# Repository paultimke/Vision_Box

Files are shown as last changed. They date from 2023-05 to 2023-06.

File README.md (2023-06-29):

# Vision Box User Interface Quality Assessment System
The Vision Box is a Computer-Vision-based system designed to automate testing of screens during the development phases of a User Interface. The physical system consists of an enclosed box to ensure a light-controlled environment for any device introduced and containts an illumination system which can be set manually or automatically through the accompanying Desktop Command-Line application.

All commands supported by the Dekstop application can be displayed using the HELPME command. Some of the main commands for a testing session are:
- **FICON**: Find a specific icon or subimage embedded within a larger image
- **COMPIMAGE**: Compare two images for similarity, returning a total similarity score
- **FTEXT**: Find specific Ascii-based text (words, letters, sentences) within the screen

## Usage Example
Imagine you have created a new screen for the UI and have an image called 'test\_screen.png'. You also have an image of an asset you want to look for in that screen. The following example of a test session will look for the asset within the image, compare the device-under-test to the screen reference provided and look for the keyword "network" within the device-under-test:

```
TESTSTATUS(START)

Initializing Hardware

TEST STARTED
[PC] >> FICON("clock.png")
[VB] >> ACK FICON(clock.png)
[PC] >> COMPIMAGE("test_screen.png")
[VB] >> ACK COMPIMAGE(test_screen.png)
[PC] >> FTEXT("network")
[VB] >> ACK FTEXT(network)
[PC] >> TESTSTATUS(END)
[VB] >> ACK TESTSTATUS(END)

Waiting on commands to finish processing...
Test result: PASSED
```
The images used on the above session were the following:
images_dut

After the test, the following output images and log file will be produced:
<p float="left">
  output
</p>

## Images of the physical device built
physical

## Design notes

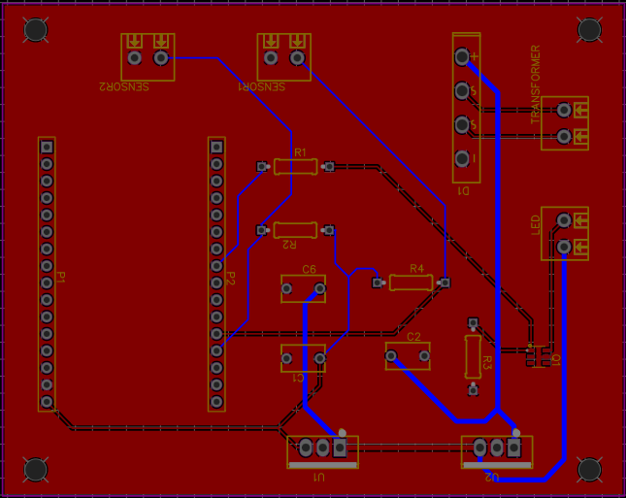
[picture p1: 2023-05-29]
Electrical/PCB_Design_brd_pdf.png

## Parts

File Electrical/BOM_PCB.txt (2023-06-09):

									
ID	Name	Designator	Quantity	Manufacturer Part	Manufacturer	Supplier	Supplier Part	Price	
1	4.7u	"C1,C6"	2	CCBCapacitor 100PF100v	ReliaPro	LCSC	C50140	0.048	
2	220u	C2	1	CCBCapacitor 100PF100v	ReliaPro	LCSC	C50140	0.048	
3	GBU406 Rectifier bridge	D1	1	GBU406	MDD	LCSC	C13432	0.19	
4	Screw_terminal_LED	E3	1	WJ350V-3.96-2P-14-00A	KANGNEX	LCSC	C3031444	0.081	
5	Header-Female-2.54_1x16	"P1,P2"	2	2.54-1*16P母	BOOMELE	LCSC	C66987	0.104	
6	SIL3439K	Q1	1	DMC2700UDM-7	DIODES	LCSC	C444426	0.193	
7	Resistor 330	R1	1	KNP5W-0Ω33±5%-CP	VO	LCSC	C5144921	0.197	
8	Resistor 10k	"R2,R4, R3"	2	CR3W-10K±5%-9T73	VO	LCSC	C2903386	0.0414	
9	Screw Terminal	"E1, E2"	2	WJ350V-3.96-2P-14-00A	KANGNEX	LCSC	C3031444	0.081	
10	Screw_terminal_Transformer	T	1	WJ350V-3.96-2P-14-00A	KANGNEX	LCSC	C3031444	0.081	
11	LM7805T	U1	1	LM7805T	HGC	LCSC	C507145	0.223	
12	LM7812L-TA3-T	U2	1	LM7812L-TA3-T	UTC	LCSC	C71108	0.234	
13	ESP 32 DEVKIT V1	U3	1	ESP32-DevKitC	Espressif Systems	Mouser	356-ESP32-DEVKITC	13

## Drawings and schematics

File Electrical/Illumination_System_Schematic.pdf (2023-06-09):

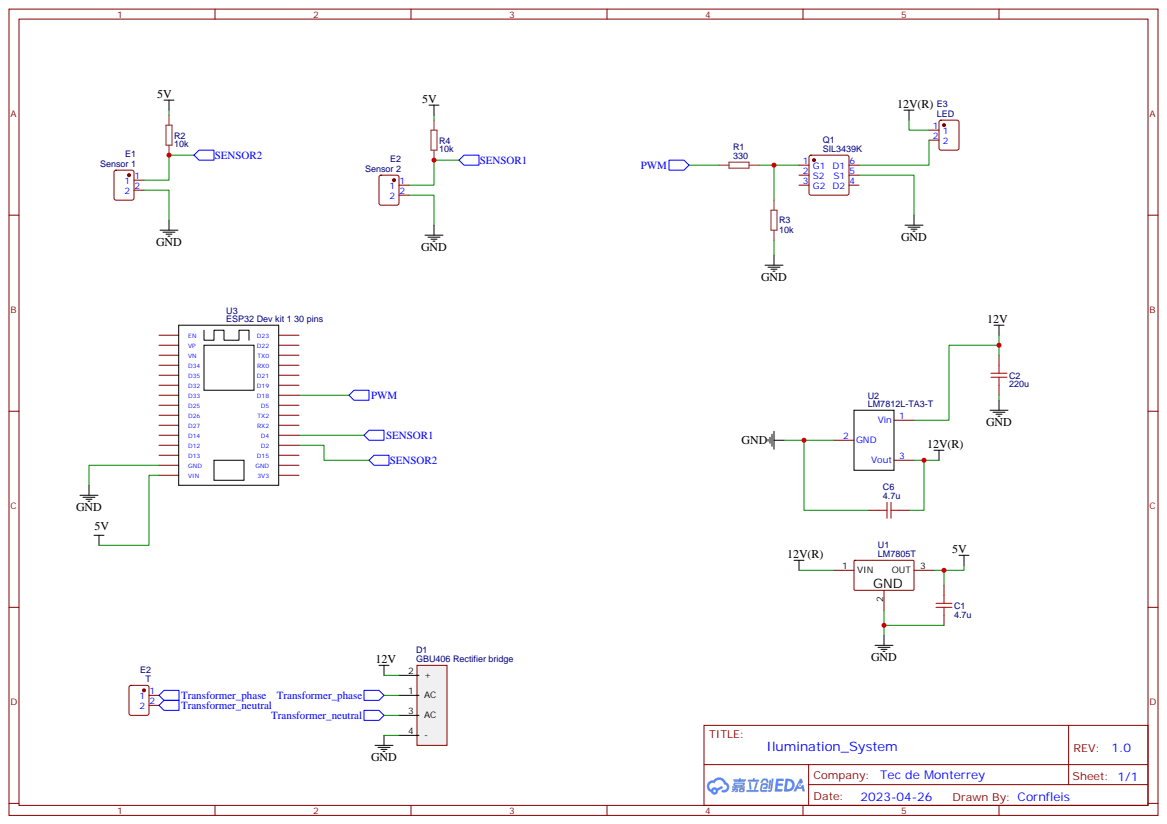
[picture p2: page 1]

Company: Tec de Monterrey

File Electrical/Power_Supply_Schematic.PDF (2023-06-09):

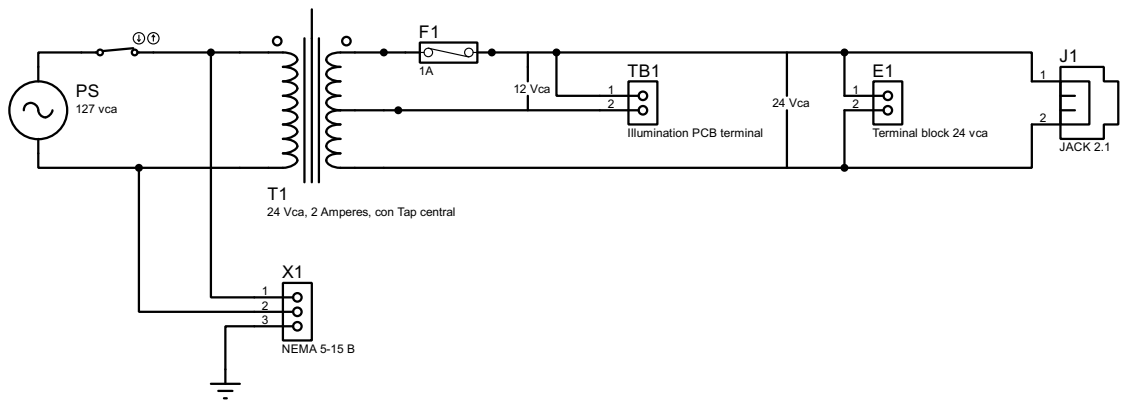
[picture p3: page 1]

24 Vca, 2 Amperes, con Tap central

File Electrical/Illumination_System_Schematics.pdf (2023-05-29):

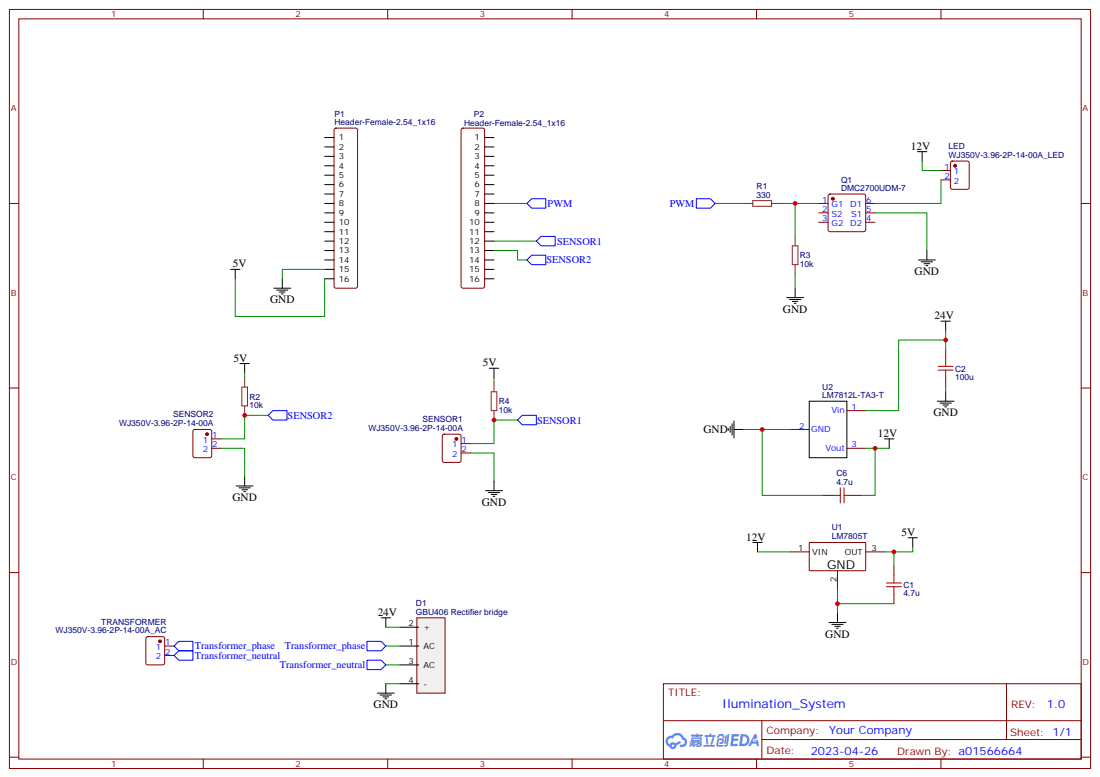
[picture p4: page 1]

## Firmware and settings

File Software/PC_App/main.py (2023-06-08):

import os
os.environ["OPENCV_VIDEOIO_MSMF_ENABLE_HW_TRANSFORMS"] = "0"
import threading
import sys
import time
import cv2
import takeFunction as parser
import constants as cnst
import find_object as fOBJ
from comp_img import compare_image
from detect_text import find_text
from set_light import Set_light
from help import help_cmd, example_cmd
from vbox_logger import logger

############################### Global variables ##############################
cmd_queue = []
failed_commands = []
mutex = threading.Lock()

class print_flag:
    vision_cmds_ran = False

cmd_lookup_table = {
    'FICON': fOBJ.mainly,
    'FTEXT': find_text,
    'COMPIMAGE': compare_image,
    'SETLIGHT': Set_light,
    'HELPME': help_cmd,
    'EXAMPLE': example_cmd
}

########################### Main Program Functions ############################
def main():
    # Get command line args
    command_args = None
    if is_CLI_args_valid(sys.argv):
        command = parser.callFunction(sys.argv[1])
        command_args = command.parse()
        if sys.argv[-1] == cnst.CLI_DEBUG_FLAG_NAME:
            logger.enable_debug_level()
        
        # Do not generate log file on HELP or EXAMPLE commands
        if command_args[0] != 'HELPME' and command_args[0] != 'EXAMPLE':
            logger.preamble_log()
        else:
            logger.close_file()
            os.remove(cnst.DEFAULT_LOG_FILE_NAME)
    else:
        exit()

    # Call corresponding command
    match command_args:
        case ('TESTSTATUS', condition):
            print('Initializing hardware')
            if condition == 'START':
                # Start CLI and command-servicing threads
                cli = threading.Thread(target=CLI_handler, args=(condition, ), daemon=True)
                cmd_server = threading.Thread(target=process_command, daemon=False)
                cli.start()
                cmd_server.start()
                cli.join()
            elif condition == 'END':
                print("Error: Can not end TESTSTATUS if none is started before")
        case (None, None):
            logger.error("VB", "Command call Syntax Error")
            return
        case (cmd, arg):
            process_command(cmd, arg)
        case _:
            logger.error("VB", "Unknown Error")
    # Log final results
    if len(failed_commands) == 0 and print_flag.vision_cmds_ran:
        print("Test result: PASSED")
        logger.info("VB", f'\nPASSED')
    elif len(failed_commands) > 0 and print_flag.vision_cmds_ran:
        print("Test result: FAILED")
        logger.info("VB", f'FAILED lines: {failed_commands}')
# END main()

def CLI_handler(condition: str):
    """ Thread to handle user CLI input """
    end = False
    if condition == 'START':
        print("\nTEST STARTED")
        logger.info("PC", "TESTSTATUS(START)")
        while not end:
            # Get string input from terminal
            input_str = input("[PC] >> ")
            command = parser.callFunction(input_str)
            (cmd, arg) = command.parse()

            # Log received command to log file
            logger.info("PC", f"{cmd}({arg})")
            print(f"[VB] >> ACK {cmd}({arg})")

            # Take image and build tuple to add to queue
            raw_input_image = None
            if cmd == 'FICON' or cmd == 'FTEXT' or cmd == 'COMPIMAGE':
                raw_input_image = inputIMG_init(cnst.DEFAULT_CAM_PORT)
            queue_params = ((cmd, arg), raw_input_image)

            # Append command to queue
            match (cmd, arg):
                case ('TESTSTATUS', 'START'):
                    logger.error("VB", "Can't start new TEST"
                                 "one is already running") 
                case ('TESTSTATUS', 'END'):
                    end = True
                    with mutex:
                        if len(cmd_queue) > 0:
                            logger.info("VB", "Command in queue")
                        print("Waiting on commands to finish processing...")
                        cmd_queue.append(queue_params)
                case (None, None):
                    logger.error("VB", f"Innvalid syntax: {input_str}")
                case _:
                    with mutex:
                        if len(cmd_queue) > 0:
                            logger.info("VB", "Command in queue")
                        cmd_queue.append(queue_params)
    else:
        # TESTSTATUS(END) was called before starting a TEST
        logger.error("Can not end a not started TESTSTATUS")
# END CLI_handler()

def process_command(cmd=None, arg=None):
    """ Thread to handle command processing. It takes commands\
        out of the common cmd_queue """
    def execute_command(cmd, arg, raw_im):
        if cmd == 'FICON' or cmd == 'FTEXT' or cmd == 'COMPIMAGE': 
            print_flag.vision_cmds_ran = True
        status = cmd_lookup_table[cmd](arg, raw_im)
        if status is not None:
            failed_commands.append(status)

            
    # Commands were given directly and no concurrency is happening
    if (cmd, arg) != (None, None):
        raw_input_image = None
        if cmd == 'FICON' or cmd == 'FTEXT' or cmd == 'COMPIMAGE': 
            raw_input_image = inputIMG_init(cam_port=cnst.DEFAULT_CAM_PORT)
        elif cmd == 'SETLIGHT':
            print("SETLIGHT command must be used inside a TESTSTATUS")
            return
        execute_command(cmd, arg, raw_input_image)
        return

    # TESTSTATUS was started, and cmd_queue is being filled by other thread
    commands_pending = False
    while True:
        with mutex:
            if len(cmd_queue) > 0:
                ((cmd, arg), raw_input_image) = cmd_queue.pop(0)
                commands_pending = True
        
        if commands_pending:
            commands_pending = False
            if (cmd, arg) == ('TESTSTATUS', 'END'):
                break
            else:
                execute_command(cmd, arg, raw_input_image)
# END process_command()
            

def is_CLI_args_valid(args):
    valid = False
    # Powershell takes parentheses differently than command prompt and already 
    # separates input. Hence, correct command will have three values. Concatenate
    # them to treat them equally as cmd prompt
    def match_PS_cmdPrompt_formats():
        command = sys.argv[1]
        command_arg = sys.argv[2]
        sys.argv.clear()
        sys.argv.append(command)
        sys.argv.append(f"{command}({command_arg})")


    match(len(args)):
        case 4:
            match_PS_cmdPrompt_formats()
            if args[3] == cnst.CLI_DEBUG_FLAG_NAME:
                valid = True
                match_PS_cmdPrompt_formats()
            else:
                logger.error("VB", f"Unknown argument {args[3]}")
        case 3:
            # 3rd argument could be Debug flag on cmd_prompt or command ran in powershell
            valid = True
            unknown_arg = args[2]
            if args[2] != cnst.CLI_DEBUG_FLAG_NAME:
                match_PS_cmdPrompt_formats()
            if args[0][:4] == args[1][:4]:
                valid = False
                print(f"Error: Unknown argument {unknown_arg}")
        case 2:
            valid = True
        case _:
            print(f"Error: Provide argument in the form COMMAND(ARG)")
            logger.error("VB", f"Argument is not in the form COMMAND(ARG)")
    return valid
# END is_CLI_args_valid()

def inputIMG_init(cam_port: str):
    """ Take image capture from camera """
    if cam_port == "0" or cam_port == "1" or cam_port == "2" or cam_port == "3" or cam_port == "4":
        cam = cv2.VideoCapture(int(cam_port), cv2.CAP_DSHOW)
        time.sleep(0.2)
        for i in range(0,6):
            _,input_image = cam.read() 
            time.sleep(0.2)
        cv2.waitKey(1)       
        cam.release()
    else:
        input_image = cv2.imread(cam_port)
        assert input_image is not None, "Failed to take picture, check camera port"

    if input_image is None:
        print("ERROR: Can not open camera")
    input_image = cv2.rotate(input_image, rotateCode= cv2.ROTATE_180)
    return input_image
            

if __name__ == '__main__':
    main()

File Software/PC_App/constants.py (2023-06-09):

################# File for handling all important constants ###################

###### General program constants
SW_VERSION_MAJOR = 0
SW_VERSION_MINOR = 1
SW_VERSION_REV = 0
PIXELS_PER_METRIC = 3.54
SOFTWARE_VERSION = f"{SW_VERSION_MAJOR}.{SW_VERSION_MINOR}.{SW_VERSION_REV}"

DEFAULT_CAM_PORT = 'Software\PC_App\Testing\screens_vbox_cam\T08_vbox_cam.png'               # Default USB port for camera
DEFAULT_LOG_FILE_NAME = "vbox.log"    # Default file name for log
OUTPUT_IMAGES_DIR = "output_images"   # Output images directory
CONFIG_FILE_NAME = "config.json"      # File name for configuration
CLI_DEBUG_FLAG_NAME = "-verbose"      # CLI argument name to trigger verbose output

###### FIND OBJECT constants
FOBJ_GRAY_THRESHOLD = 100             # Threshold for input image grayscale (0 - 255)
FOBJ_RESIZE_INPUT_STD = (2400, 2400)  # Standard resize values for input image (x,y)
FOBJ_RESIZE_TEMP_STD = 100            # Template resize (pixels)
FOBJ_MATCH_THRESHOLD = 73             # Acceptance threshold for matching template # Used to be 50, TODO: Ask @christian 
FOBJ_ACCEPTANCE_DIFF = 30             # Acceptance difference between found objects
FOBJ_MT_ITERATIONS = 100              # Iterations to apply Match template algorithm

##### COMPARE IMAGE constants
CIMG_IOU_MATCH_THRESHOLD = 0.5
CIMG_TEXT_MATCH_THRESHOLD = 0.6


##### PIXEL CONVERTER constants
DIAMETER_10_COIN = 28                 # 10 pesos coin diameter is 28 mm 

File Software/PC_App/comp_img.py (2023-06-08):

import cv2
import os
import numpy as np
import matplotlib.pyplot as plt
from typing import List, Tuple
from crop_screen import StraightenAndCrop, StraightenAndCrop_Calibrated
from vbox_logger import logger, img_logger
import constants as cnst
import detect_text

# Box type (x, y, w, h) where (x,y) is Top-Left and (w,h) are width and height
box_t = Tuple[int, int, int, int]

LOG_TAG = 'COMPIMAGE'

############################### HELPER FUNCTIONS ##############################
def img_show(img_list: List[cv2.Mat]):
    """ Shows a list of images """
    if len(img_list) == 1:
        plt.imshow(cv2.cvtColor(img_list[0], cv2.COLOR_BGR2RGB))
    else:
        _, imarr = plt.subplots(1, len(img_list))
        for i in range(len(img_list)):
            imarr[i].imshow(cv2.cvtColor(img_list[i], cv2.COLOR_BGR2RGB))

def img_preprocess_IoU_ref(img: cv2.Mat) -> cv2.Mat:
    """ Processes an image to make it ready for IoU comparison """
    # Binarize
    new_img = cv2.cvtColor(img, cv2.COLOR_BGR2GRAY)
    new_img = cv2.adaptiveThreshold(new_img, 255, cv2.ADAPTIVE_THRESH_GAUSSIAN_C,
                                          cv2.THRESH_BINARY_INV, 199, 5)
    return

def img_preprocess_IoU_sample(img: cv2.Mat) -> cv2.Mat:
    """ Processes an image to make it ready for IoU comparison """
    # Binarize
    THRESH = 150
    new_img = cv2.cvtColor(img, cv2.COLOR_BGR2GRAY)
    new_img = cv2.adaptiveThreshold(new_img, 255, cv2.ADAPTIVE_THRESH_GAUSSIAN_C,
                                          cv2.THRESH_BINARY_INV, 115, 5) # GAUSSIAN 199

    # Erode
    kernel = np.ones((2, 2), np.uint8)
    new_img = cv2.erode(new_img, kernel, iterations=1)
    return new_img

def img_preprocess_Text(img: cv2.Mat):
    """ Processes an image to make it ready for text extraction """
    THRESH = 140
    img = cv2.cvtColor(img, cv2.COLOR_BGR2GRAY)
    _, img = cv2.threshold(img,THRESH,255,cv2.THRESH_BINARY)
    return img

def intersection_over_union(boxA: box_t, boxB: box_t) -> float:
    # Convert the boxes to the form (x, y, x+w, y+h)
	# to get top-left and bottom-right corners      
    boxA = (boxA[0], boxA[1], boxA[0] + boxA[2], boxA[1] + boxA[3])
    boxB = (boxB[0], boxB[1], boxB[0] + boxB[2], boxB[1] + boxB[3])

    # Determine the (x, y) - coordinates of the intersection rectangle
    xA = max(boxA[0], boxB[0])
    yA = max(boxA[1], boxB[1])
    xB = min(boxA[2], boxB[2])
    yB = min(boxA[3], boxB[3])
    # Compute the area of input rectangles and their intersection rectangle
    interArea = max(0, xB - xA) * max(0, yB - yA)
    boxAArea = (boxA[2] - boxA[0]) * (boxA[3] - boxA[1])
    boxBArea = (boxB[2] - boxB[0]) * (boxB[3] - boxB[1])
    # Compute intersection over union metric
    # Intersection area must be subtracted to avoid counting it doubly
    iou = interArea / float(boxAArea + boxBArea - interArea)
    return iou

def img_getSimilarity(sample_boxes: List[box_t], ref_boxes: List[box_t]) -> float:
    boxesA = sample_boxes.copy()  # Make copies to avoid mutation of inputs
    boxesB = ref_boxes.copy()     # Make copies to avoid mutation of inputs
    iou_thresh = 0.15         # Threshold to trigger successful IoU match
    IoU_matches = []          # Stores succesful IoU match values
    
    while len(boxesA) > 0:
        max_IoU = 0
        Bbox_to_delete = None
        for i in range(len(boxesB)):
            iou = intersection_over_union(boxesA[0], boxesB[i])
            if iou > iou_thresh and iou > max_IoU:
                max_IoU = iou
                Bbox_to_delete = boxesB[i]
        if max_IoU != 0:
            IoU_matches.append(max_IoU)
            boxesB.remove(Bbox_to_delete)
    		
    	# Remove first item in boxes list until process complete
        boxesA.pop(0)
    return (len(IoU_matches)/len(ref_boxes))

def CompareText(sample_img: cv2.Mat, ref_img: str) -> float:
    sample_img = img_preprocess_Text(sample_img)

    # Read all words in both images and delete temporary img after done
    sample_words = [wrd[0] for wrd in detect_text.find_all_words(sample_img)]
    ref_words = [wrd[0] for wrd in detect_text.find_all_words(ref_img)]

    # Compare words
    matches = 0
    union_length = max(len(ref_words), len(sample_words))
    for sw in sample_words:
        for rw in ref_words:
            if sw == rw:
                matches += 1
                ref_words.remove(rw)
                break
        
    text_sim = matches/union_length
    logger.debug("VB", f"Image text similarity: {text_sim}", tag=LOG_TAG)
    return text_sim
    
def CompareIoU(sample_img: cv2.Mat, ref_img: cv2.Mat) -> float:
    # Preprocess Images for Structural Similarity test
    SAMPLE_PROCESSED = img_preprocess_IoU_sample(sample_img)
    REF_PROCESSED = img_preprocess_IoU_ref(ref_img)
    SAMPLE_PROCESSED = cv2.resize(SAMPLE_PROCESSED, 
                                    (REF_PROCESSED.shape[1], REF_PROCESSED.shape[0]))

    # Calculate bounding boxes
    contours_sample, _ = cv2.findContours(SAMPLE_PROCESSED, cv2.RETR_TREE, cv2.CHAIN_APPROX_SIMPLE)
    contours_ref, _ = cv2.findContours(REF_PROCESSED, cv2.RETR_TREE, cv2.CHAIN_APPROX_SIMPLE)
    boxes_sample = [cv2.boundingRect(cnt) for cnt in contours_sample]
    boxes_ref = [cv2.boundingRect(cnt) for cnt in contours_ref]
    
    # Calculate similarity
    sim = img_getSimilarity(boxes_sample, boxes_ref)
    logger.debug("VB", f"Structural similarity: {round(sim, 2)}", tag=LOG_TAG)
    return sim

def compare_image(ref_path: str, sample_img: cv2.Mat) -> int:
    # Read images
    if sample_img is None:
        logger.warning("VB", "Image could not be read from camera", tag=LOG_TAG)
        return
    try:
        ref_img = cv2.imread(ref_path)
        if ref_img is None:
            logger.warning("VB", "Could not read image from provided path", tag=LOG_TAG)
            return 
    except:
        logger.warning("VB", "Could not read image from provided path", tag=LOG_TAG)
        return

    # First crop sample_img to show only screen of device
    sample_img = StraightenAndCrop_Calibrated(sample_img, 
                                              ref_img.shape[1], 
                                              ref_img.shape[0])

    # Save images
    img_logger.img_save(LOG_TAG, [sample_img, ref_img])

    # Compute comparison metrics
    iou_sim = CompareIoU(sample_img, ref_img)
    if iou_sim < cnst.CIMG_IOU_MATCH_THRESHOLD:
        logger.info("VB", "FAILED", tag=LOG_TAG)
        log_line_num = logger.curr_line_num
        return log_line_num
    
    text_sim = CompareText(sample_img, ref_img)
    if text_sim < cnst.CIMG_TEXT_MATCH_THRESHOLD:
        logger.info("VB", "FAILED", tag=LOG_TAG)
        log_line_num = logger.curr_line_num
        return log_line_num
    
    # If execution got here, test is PASSED
    logger.info("VB", "PASSED", tag=LOG_TAG)
    return None
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

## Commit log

2023-04-29 CORN-21: Added PWM module for LED brightness control
2023-05-06 Electrical folder
    Illumination schematic, gerber, BOM
    Power supply Schematic
    [Illumination_System_BOM.csv]
2023-05-17 Added accessKey file for AWS text recognition
    [Visionbox_accessKeys.csv]
2023-05-17 Find objects filtered by correlation values
2023-05-27 Add camera port constant
2023-05-29 New electrical files
    update
    [Illumination_System_BOM.csv]
2023-05-29 Updates
    New PCB brd file
    Change power supply schematic, with pcb
2023-05-29 LTSpice simulation of Board Supply
2023-05-30 PWM usage example
2023-06-01 FW: Change pwm file headers
2023-06-01 Add new test images
    Added new test images taken for the first time
    on the actual Vision Box enclosure
2023-06-01 Added calibration tool GUI to select corners
    GUI to select the corners of the screen
2023-06-01 Added function to use calibrated screen corners
    There are now to options to straighten and crop images: Automated Detection and with Calibrated Data
2023-06-03 Remove print error on quoation marks
    When running the program on Command Prompt or Poweshell (both windows), quotation marks are handled differently. Powershell ran commands were printing this error message incorrectly
    [takeFunction.py]
2023-06-03 Update main.py to use threads
2023-06-05 Add automatic line counting on logger
    A wrapper around python's own logging module was made to increment line numbers automatically on each call to a logging function. A function to print a preamble to log file was also added.
2023-06-05 Fix bug on matching Powershell and Command Prompt formats
    [main.py]
2023-06-05 Fix bug where process_command got stuck on infinite loop
    process_command function got stuck if program was ran with single command rather than TESTSTATUS, as it kept waiting for further commands to come where there weren't any
    [main.py]
2023-06-05 Fix bug on debug logging
    Debug logs were not getting printed as debug level is handled locally inside class and hence level on python's module is never set
    [vbox_logger.py]
2023-06-05 Update set_light to be more platform independent
    Serial tools may behave a bit differently on Windows and POSIX systems. Added buffer flushes, time delays and reversed port lists to make system faster and more robust on both platforms
    [set_light.py]
2023-06-05 Update logger to have consistent spacing
    Logging spacings were varying if the tag was empty. This fix handles that issue
    [vbox_logger.py]
2023-06-05 Add invalid syntax error log
    [main.py]
2023-06-05 Avoid generation of log file on Help commands
    HELPME and EXAMPLE commands no longer generate a log file
    [main.py]
2023-06-05 Fix spacing issue on log warnings
    [vbox_logger.py]
2023-06-06 Change CLI_handler to be daemon thread
    Some commands were not executing as cmd_server thread was set to daemon instead of the CLI_handler thread.
2023-06-06 loggers for detect_text.py
    info, error, and debug logger added for text recognition and aws conenction
    [detect_text.py]
2023-06-06 Update detect_text.py
    fix the index for the logger so it would start in 1
    [detect_text.py]
2023-06-06 Update calibration tool to read from camera
2023-06-06 Change calibration tool font scale
2023-06-06 Workaround on long camera startup time
    [main.py]
2023-06-06 Add missing wireframes
2023-06-06 Declare function prototype for image logger
2023-06-06 Update to avoid image capture on non-vision commands
    [main.py]
2023-06-06 Fix issue where capture was not taken on commands
    [main.py]
2023-06-07 Update set_light to avoid esp32 resetting on close
    [set_light.py]
2023-06-07 Remove unnecessary prints
2023-06-07 Issue on FICON parsing workaround
    [takeFunction.py]
2023-06-07 Current line logger return in detect text
    Return current line logger
2023-06-07 Log images and use calibration on detect_text
2023-06-07 Add error message when cam not opened
    [main.py]
2023-06-07 Prohibit SETLIGHT case outside teststatus
2023-06-07 COMPIMG return log line_nums
    Returns log line number if FAILED, None if PASSED
    [comp_img.py]
2023-06-07 Fix bug where prints were made on bad positions
    [main.py]
2023-06-07 Remove print on set_light
2023-06-07 Update calibration tool to do dimensions calibration
2023-06-09 New documents
    [Illumination_System_BOM.csv]
2023-06-28 Deleted non-current electrical documents
2023-06-28 Removed testing images, scripts and wireframes from version control
2023-06-29 Update README.md
    Add images of physical device
